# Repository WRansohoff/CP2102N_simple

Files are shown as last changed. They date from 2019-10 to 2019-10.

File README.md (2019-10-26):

# CP2102N USB \<-\> UART Board

This is a simple reference implementation of a board using the `CP2102N` USB / Serial bridge. It has a micro-USB connector on one side, and TX / RX / 3.3V / Ground pins on the other.

The other USART signals provided by the `CP2102N` are also broken out on two rows of headers along the side of the board. I haven't tested them because I don't usually use those signals, but it seemed like a good idea to make them available.

# Current Status

This is the second revision of a design that I've had some success with. I've only tested the TX / RX signals, but those seem to work fine.

I'm still waiting to receive boards with this actual design, though, so you should still think of this board as untested for now.

# Schematic and Board Renders

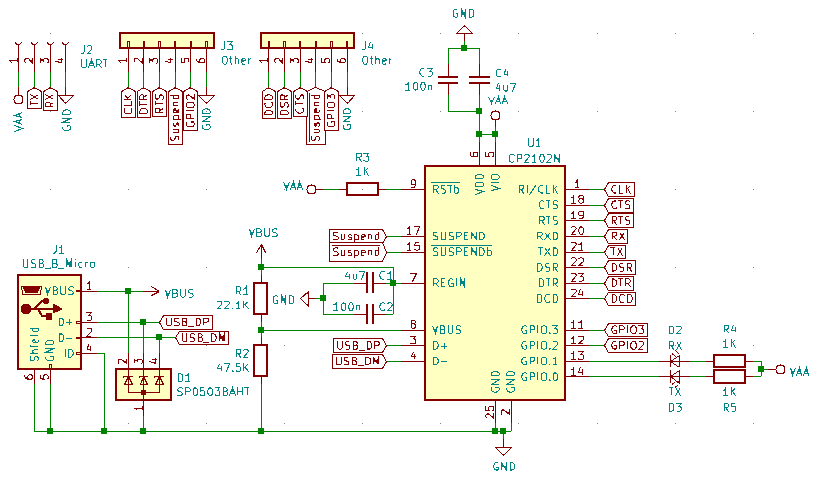
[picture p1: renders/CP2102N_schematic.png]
Schematic


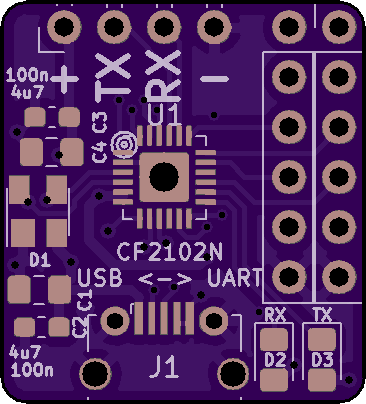
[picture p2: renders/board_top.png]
Board Top

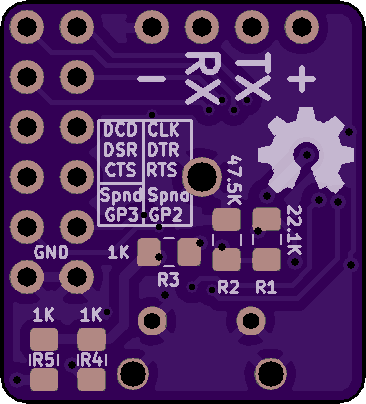
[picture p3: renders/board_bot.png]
Board Bottom


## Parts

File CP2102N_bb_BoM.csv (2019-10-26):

Part ID | Part type | Part size (Imperial) | Part value | Example Digikey Item(s) | Cost (qty: x) | Comment
C1, C4 | Capacitor | 0805 | 4.7 μF | https://www.digikey.com/short/pdb9mj | $0.26
C2, C3 | Capacitor | 0603 | 100 nF | https://www.digikey.com/short/pdb948 | $0.20
D1 | TVS Diode Network | SOT-143-4 | SP0503 | https://www.digikey.com/short/pdhfqd | $0.82 | 3-in-1 TVS diodes for USB data line filtering. These diodes should protect the two differential data lines and the positive power line.
D2, D3 | LED | 0805 | Any Colors | https://www.digikey.com/short/pdb9m9 https://www.digikey.com/short/pdb9hq | $0.34 | "Transmit" and "receive" LEDs - use whatever colors you prefer. D2 is "receive", D3 is "transmit". It's probably a good idea to use different colors.
J1 | USB Connector | Micro-B Socket | N/A | https://www.digikey.com/short/pdhw81 | $2.07 | Micro-USB connector for battery charging and USB communication. I'm still working through a reel of cheap-o micro-B sockets that I ordered awhile ago, but they seem to fit the "Wuerth_629105150521" footprint in KiCAD.
J2 | Pin Header | 0.1" | 1x4 | https://www.digikey.com/short/pdhw3q | $0.13 | Main UART header: "+3.3V", "RX", "TX", and "Ground".
J3, J4 | Pin Header | 0.1" | 1x6 | https://www.digikey.com/short/pdb983 | $0.32 | Headers for other USART signals.
R1 | Resistor | 0805 | 22.1 KΩ (1%) | https://www.digikey.com/short/pdb9zz | $0.10 | One of two resistors used in a voltage divider required by the internal voltage regulator.
R2 | Resistor | 0805 | 47.5 KΩ (1%) | https://www.digikey.com/short/pdb9zh | $0.10 | One of two resistors used in a voltage divider required by the internal voltage regulator.
R3, R4, R5 | Resistor | 0805 | 1 KΩ | https://www.digikey.com/short/pdb9p1 | $0.20 | R3 is the reset pin's pull-up resistor. R4 and R5 are current-limiting resistors for the "transmit" and "receive" LEDs.
U1 | USB / Serial Bridge | QFN-24 (4x4mm) | CP2102N-A01 | https://www.digikey.com/short/pdb9qt | $1.35 | The main USB / UART bridge chip.
Total: |  |  |  |  | $5.89

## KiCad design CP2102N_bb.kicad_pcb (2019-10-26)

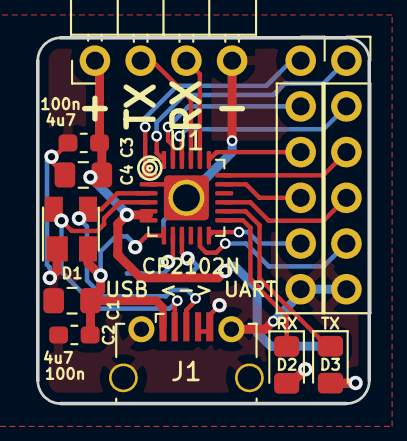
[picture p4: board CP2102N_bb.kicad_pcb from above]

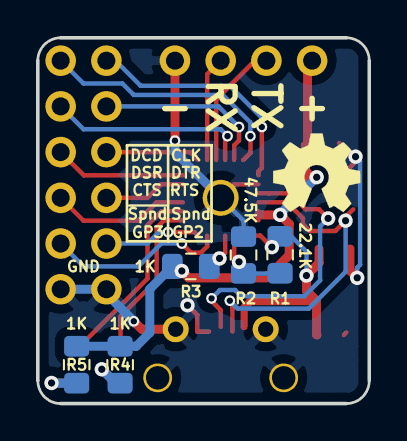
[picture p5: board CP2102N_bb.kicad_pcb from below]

Board: 2 copper layers, 18.4 x 20.3 mm, 17 parts (5 on the bottom side), 23 nets.

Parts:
C1, C4: 4u7; C_0805_2012Metric_Pad1.15x1.40mm_HandSolder
C2, C3: 100n; C_0603_1608Metric_Pad1.05x0.95mm_HandSolder
D1: SP0503BAHT; SOT-143
D2: RX; LED_0805_2012Metric_Pad1.15x1.40mm_HandSolder
D3: TX; LED_0805_2012Metric_Pad1.15x1.40mm_HandSolder
J1: USB_B_Micro; MyMicroUSB
J2: UART; PinHeader_1x04_P2.54mm_Horizontal
J3, J4: Other; PinSocket_1x06_P2.54mm_Vertical
R1: 22.1K; R_0805_2012Metric_Pad1.15x1.40mm_HandSolder
R2: 47.5K; R_0805_2012Metric_Pad1.15x1.40mm_HandSolder
R3, R4, R5: 1K; R_0805_2012Metric_Pad1.15x1.40mm_HandSolder
U1: CP2102N; QFN-24-1EP_4x4mm_HandSolder

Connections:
CLK: J3.1, U1.1
CTS: J4.3, U1.18
DCD: J4.1, U1.24
DSR: J4.2, U1.22
DTR: J3.2, U1.23
GND: C1.2, C2.2, C3.2, C4.1, D1.1, J1.4, J1.5, J1.6, J2.4, J3.6, J4.6, R2.1, U1.2, U1.25
GPIO2: J3.5, U1.12
GPIO3: J4.5, U1.11
unnamed: D2.1, U1.13
unnamed: D2.2, R4.2
unnamed: D3.1, U1.14
unnamed: D3.2, R5.1
unnamed: R1.1, R2.2, U1.8
unnamed: R3.1, U1.9
RTS: J3.3, U1.19
RX: J2.3, U1.20
Suspend: J3.4, U1.17
TX: J2.2, U1.21
USB_DM: D1.4, J1.2, U1.4
USB_DP: D1.3, J1.3, U1.3
VAA: C3.1, C4.2, J2.1, R3.2, R4.1, R5.2, U1.5, U1.6
VBUS: C1.1, C2.1, D1.2, J1.1, R1.2, U1.7
~Suspend: J4.4, U1.15

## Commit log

2019-10-26 Add Bill of Materials.
    [CP2102N_bb_BoM.csv]
2019-10-26 Add schematic file.
    [CP2102N_bb.sch]
2019-10-26 Add PCB file.
    [CP2102N_bb.kicad_pcb]
2019-10-26 Add custom footprints.
2019-10-26 Add initial renders of the board.
2019-10-26 Update project to use a local version of the hand-solderable QFP-24 footprint.
    [CP2102N_bb.kicad_pcb, CP2102N_bb.sch]
